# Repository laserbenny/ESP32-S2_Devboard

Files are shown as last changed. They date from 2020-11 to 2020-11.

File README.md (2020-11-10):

# ESP32-S2_Devboard

This bare minimum board uses the ESP32-S2 module, it is designed to use minimal amount of current during sleep. All signals are routed to the edge of the PCB, it is also designed to fit in a breadboard.

The module is NOT 5V tolerant so make sure your UART is only 3.3V!  

1. To program the MCU first connect the UART to the RX, TX and GND pins.
2. Hold down RST and press BOOT, release the RST button and then the BOOT button.
3. The MCU shall now be in bootloader mode and can be programmed with Arduino

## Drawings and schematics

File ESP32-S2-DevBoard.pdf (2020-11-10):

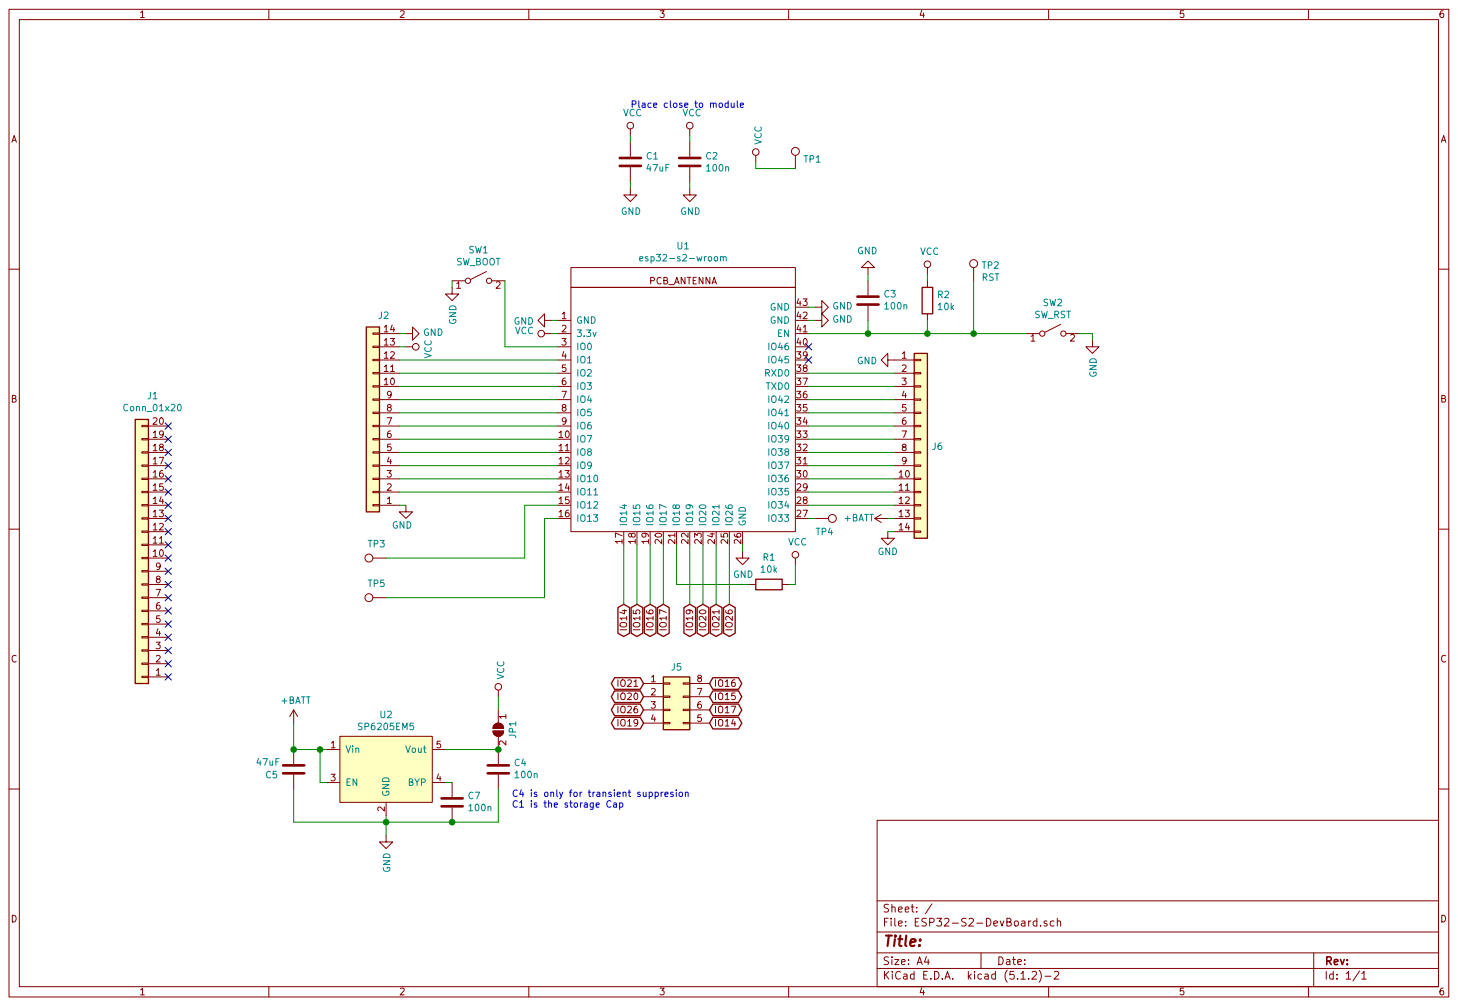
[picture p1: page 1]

C1 is the storage Cap

Id: 1/1 Title: File: ESP32-S2-DevBoard.sch Sheet: /

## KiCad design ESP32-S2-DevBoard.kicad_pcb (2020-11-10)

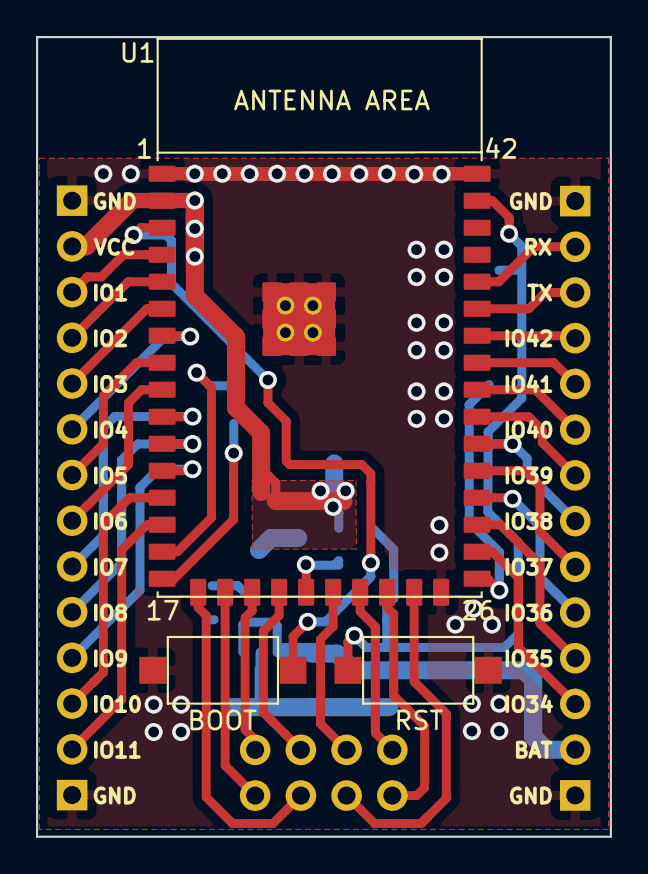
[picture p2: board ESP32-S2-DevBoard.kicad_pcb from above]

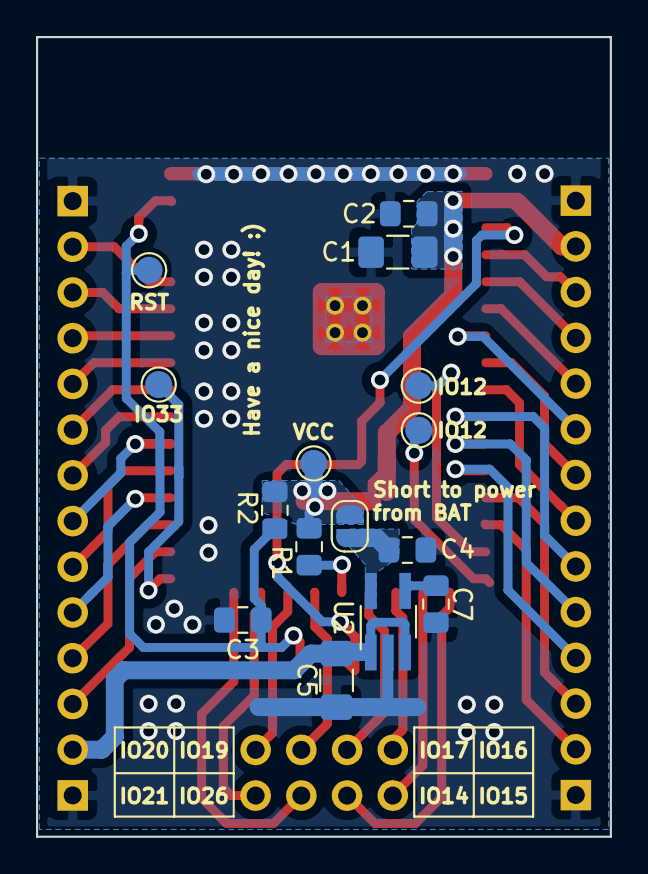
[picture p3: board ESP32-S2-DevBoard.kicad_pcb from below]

Board: 2 copper layers, 31.9 x 44.4 mm, 21 parts (15 on the bottom side), 41 nets.

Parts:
C1, C5: 47uF; C_1206_3216Metric_Pad1.42x1.75mm_HandSolder
C2, C3, C4, C7: 100n; C_0805_2012Metric_Pad1.15x1.40mm_HandSolder
J2, J6: Conn_01x14; PinSocket_1x14_P2.54mm_Vertical_2
J5: Conn_02x04_Counter_Clockwise; PinSocket_2x04_P2.54mm_Vertical2
JP1: SolderJumper_2_Open; SolderJumper-2_P1.3mm_Open_RoundedPad1.0x1.5mm
R1, R2: 10k; R_0805_2012Metric_Pad1.15x1.40mm_HandSolder
SW1: BOOT; SW_SPST_CK_RS282G05A3
SW2: RST; SW_SPST_CK_RS282G05A3
TP1: VCC; TestPoint_Pad_D1.5mm
TP2: RST; TestPoint_Pad_D1.5mm
TP3, TP5: IO12; TestPoint_Pad_D1.5mm
TP4: IO33; TestPoint_Pad_D1.5mm
U1: esp32-s2-wroom; esp32-s2-wrooom
U2: SP6205EM5; TSOT-23-5_HandSoldering

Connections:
+BATT: C5.2, J6.13, U2.1, U2.3
GND: C1.2, C2.2, C3.2, C4.1, C5.1, C7.1, J2.1, J2.14, J6.1, J6.14, SW1.1, SW2.2, U1.1, U1.26, U1.42, U1.43, U2.2
IO14: J5.5, U1.17
IO15: J5.7, U1.18
IO16: J5.8, U1.19
IO17: J5.6, U1.20
IO19: J5.4, U1.22
IO20: J5.2, U1.23
IO21: J5.1, U1.24
IO26: J5.3, U1.25
unnamed: C3.1, R2.2, SW2.1, TP2.1, U1.41
unnamed: C4.2, JP1.2, U2.5
unnamed: C7.2, U2.4
unnamed: J2.2, U1.14
unnamed: J2.3, U1.13
unnamed: J2.4, U1.12
unnamed: J2.5, U1.11
unnamed: J2.6, U1.10
unnamed: J2.7, U1.9
unnamed: J2.8, U1.8
unnamed: J2.9, U1.7
unnamed: J2.10, U1.6
unnamed: J2.11, U1.5
unnamed: J2.12, U1.4
unnamed: J6.2, U1.38
unnamed: J6.3, U1.37
unnamed: J6.4, U1.36
unnamed: J6.5, U1.35
unnamed: J6.6, U1.34
unnamed: J6.7, U1.33
unnamed: J6.8, U1.32
unnamed: J6.9, U1.31
unnamed: J6.10, U1.30
unnamed: J6.11, U1.29
unnamed: J6.12, U1.28
unnamed: R1.2, U1.21
unnamed: SW1.2, U1.3
unnamed: TP3.1, U1.15
unnamed: TP4.1, U1.27
unnamed: TP5.1, U1.16
VCC: C1.1, C2.1, J2.13, JP1.1, R1.1, R2.1, TP1.1, U1.2
